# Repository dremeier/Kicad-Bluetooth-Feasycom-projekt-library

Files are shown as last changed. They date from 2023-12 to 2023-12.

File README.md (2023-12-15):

# Kicad-Bluetooth-Feasycom-projekt-library
KiCad 7 Library for the FSC-BT1026 Module and schematic with FSC-BT1026 and PCM5102.
The Feasycom module is a fantastic choice!
It is easy to control via UART, I2C and has I2S Audio bus as well direct SPDIF per default so no deep programming is necessary.
The Documentation is perfect and you can have a cheap experimental Board in Arduino-UNO format.

hope it is usefull for someone, 
enjoiy!

[Example Bluetooth schematic](https://github.com/dremeier/Kicad-Bluetooth-Feasycom-projekt-library/blob/main/Bluetooth_FSC-BT1026x_project/Documents/Bluetooth_PCM5102_Circuit.pdf)
<object data="https://github.com/dremeier/Kicad-Bluetooth-Feasycom-projekt-library/blob/main/Bluetooth_FSC-BT1026x_project/Documents/Bluetooth_PCM5102_Circuit.pdf" type="application/pdf" width="100%">
</object>

## KiCad 3D-Package
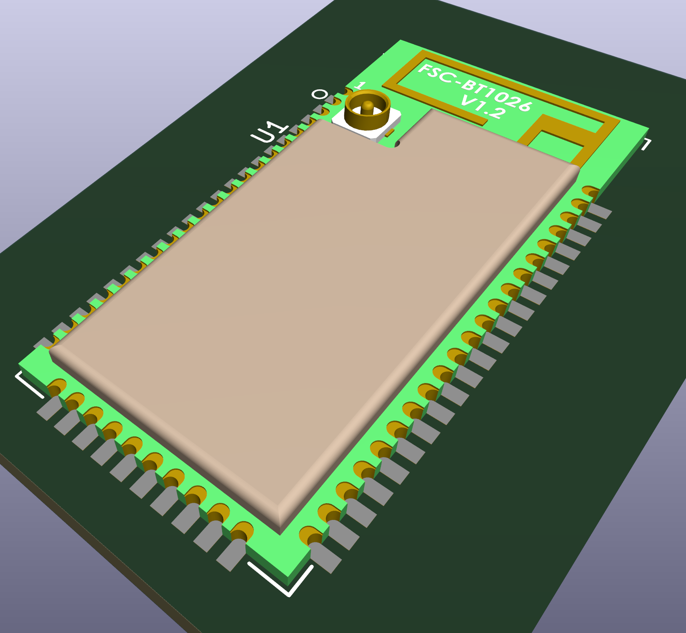
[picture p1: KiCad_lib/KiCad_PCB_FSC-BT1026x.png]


## KiCad Projekt with the Feasycom Bluetooth Module (BMW-IbusTrx-Teensy)


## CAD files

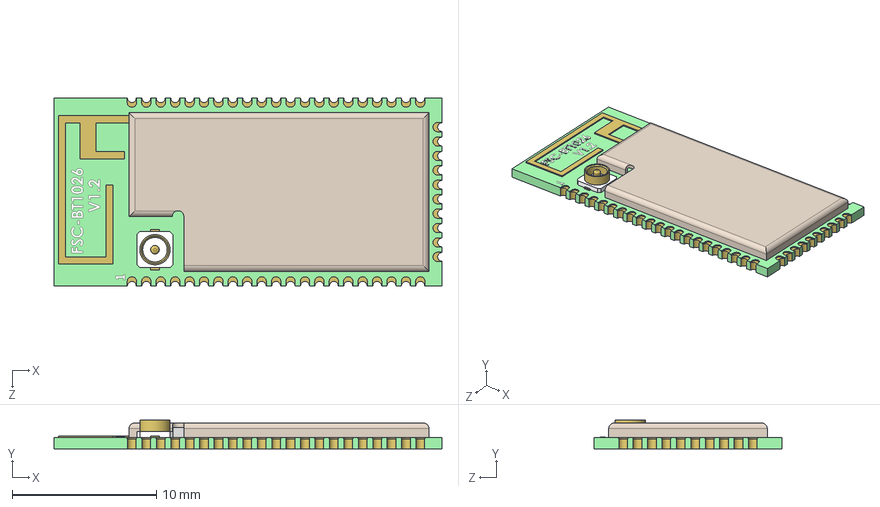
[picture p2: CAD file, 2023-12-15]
KiCad_lib/FSC-BT1026.STEP
26.9 x 2.00 x 13.0 mm

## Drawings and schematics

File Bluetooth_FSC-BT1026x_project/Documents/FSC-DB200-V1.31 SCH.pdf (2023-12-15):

6 | 5 | 4 | 3 | 2 | 1

D

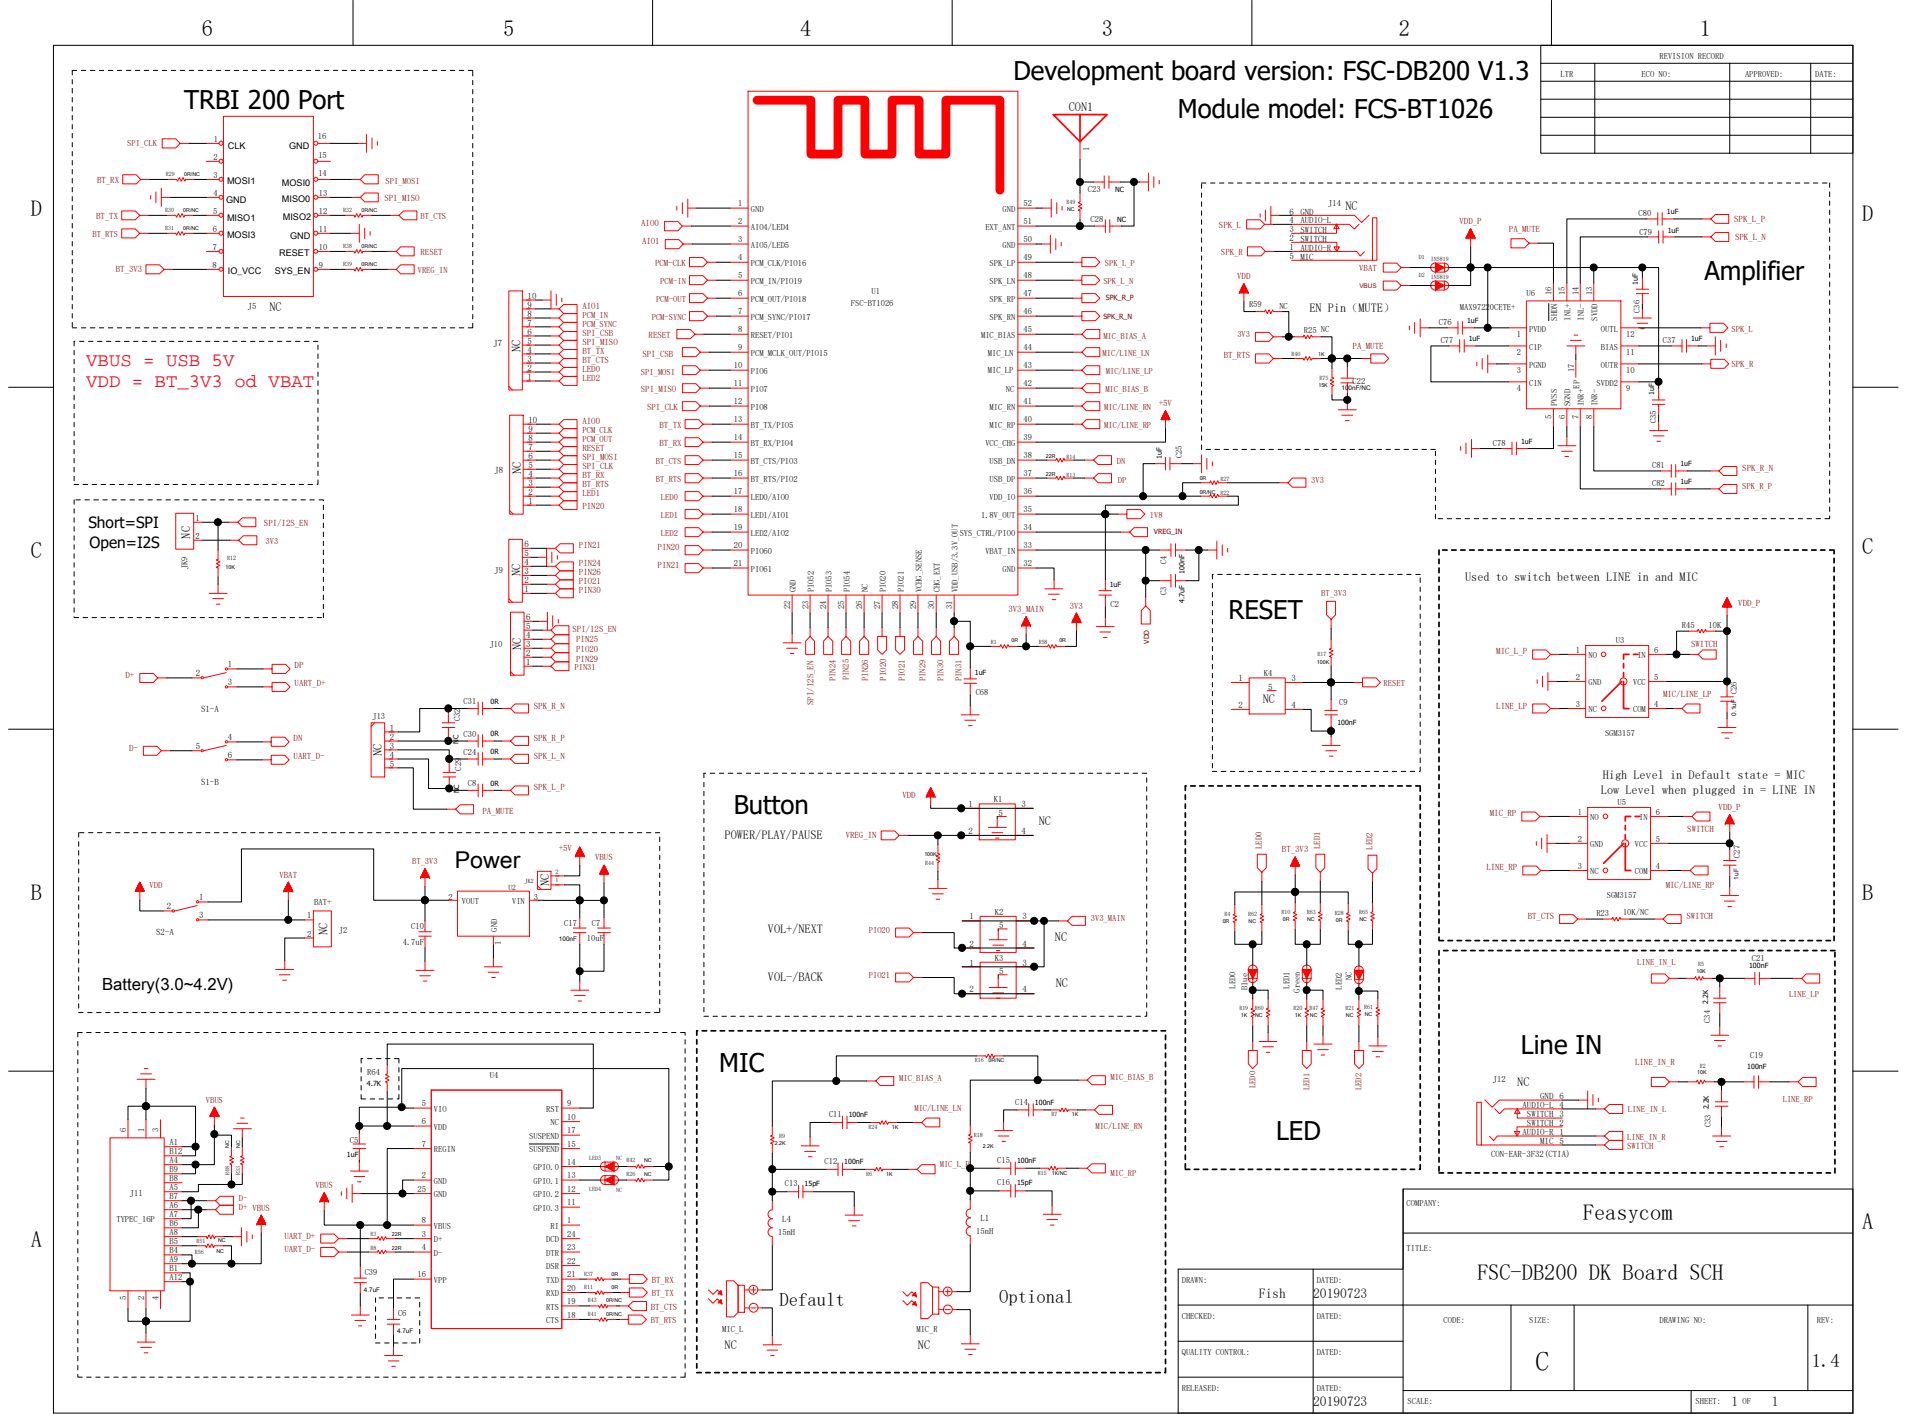
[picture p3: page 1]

Development board version: FSC-DB200 V1.

Used to switch between LINE in and MIC

High Level in Default state = MIC
Low Level when plugged in = LINE IN

FSC-DB200 DK Board SCH

CHECKED: | DATED: | CODE: | SIZE: C | DRAWING NO: | REV: 1.4

QUALITY CONTROL: | DATED:

RELEASED: | DATED: 20190723

SCALE: | SHEET: 1 OF 1

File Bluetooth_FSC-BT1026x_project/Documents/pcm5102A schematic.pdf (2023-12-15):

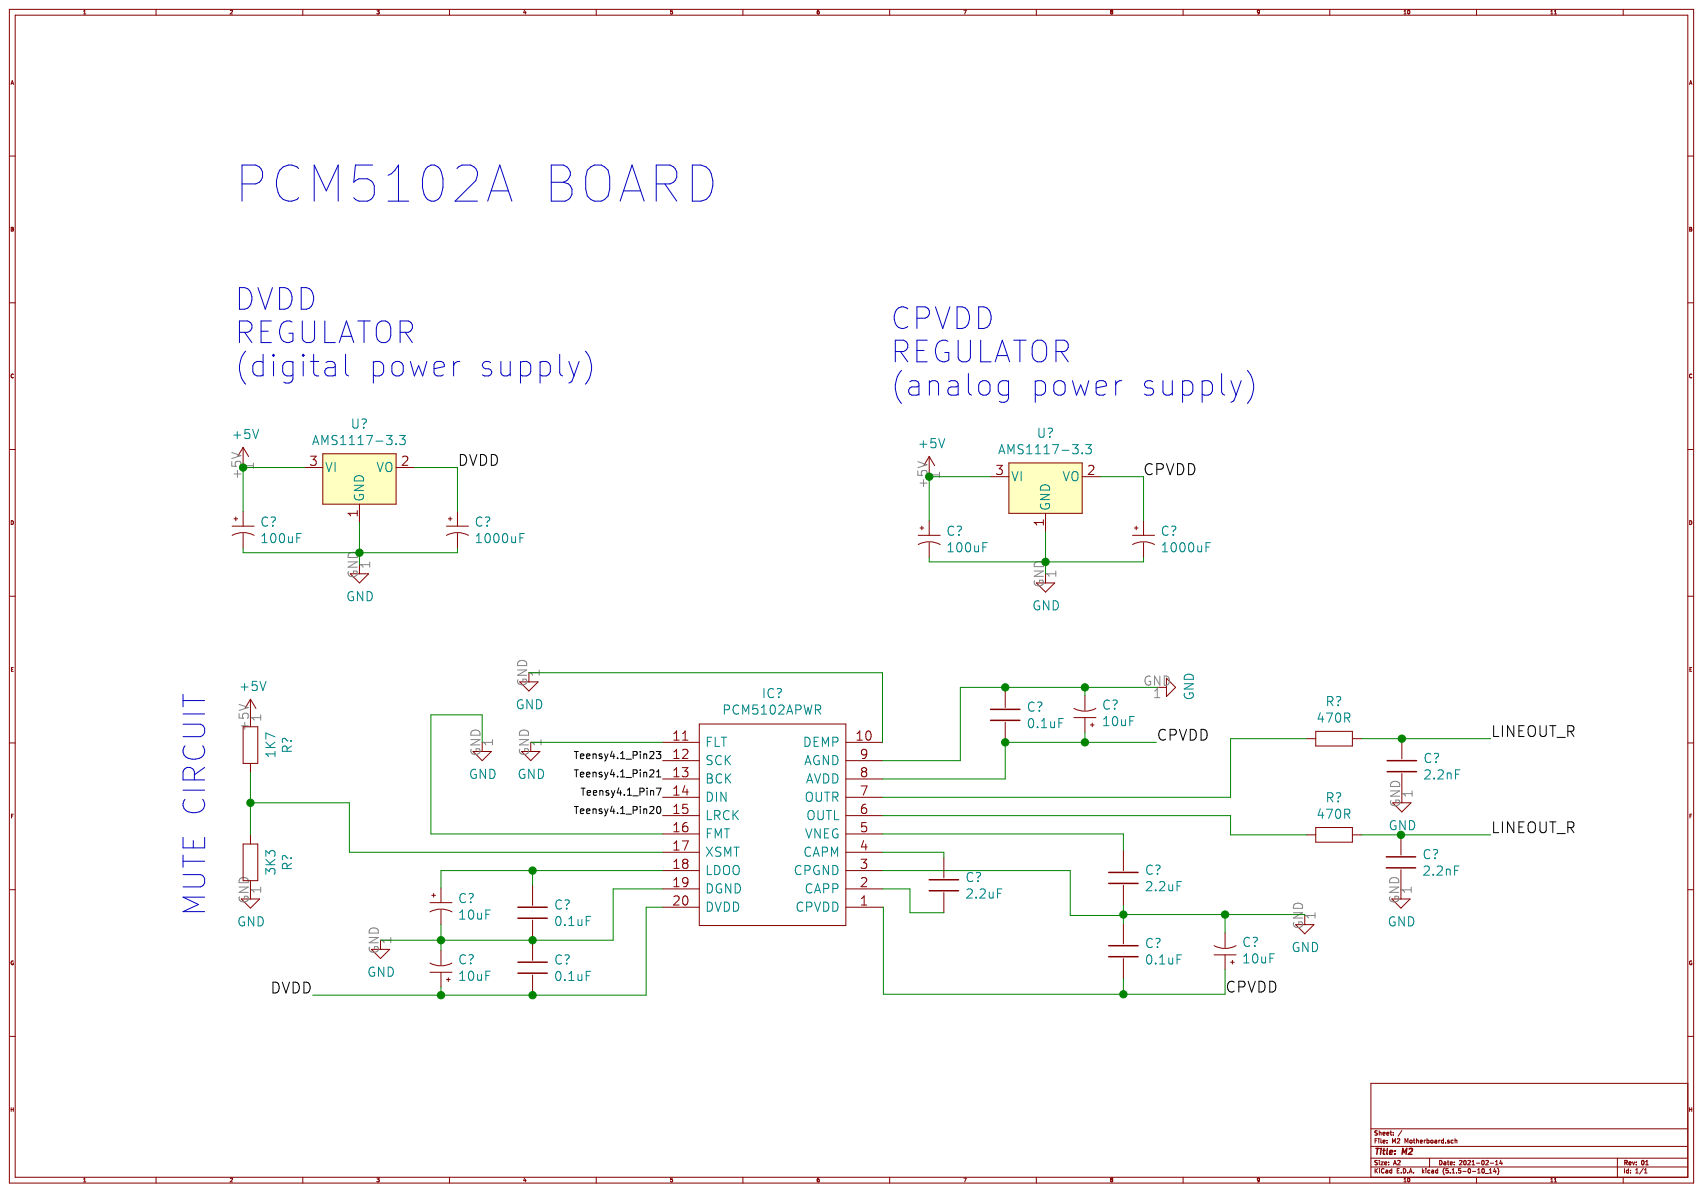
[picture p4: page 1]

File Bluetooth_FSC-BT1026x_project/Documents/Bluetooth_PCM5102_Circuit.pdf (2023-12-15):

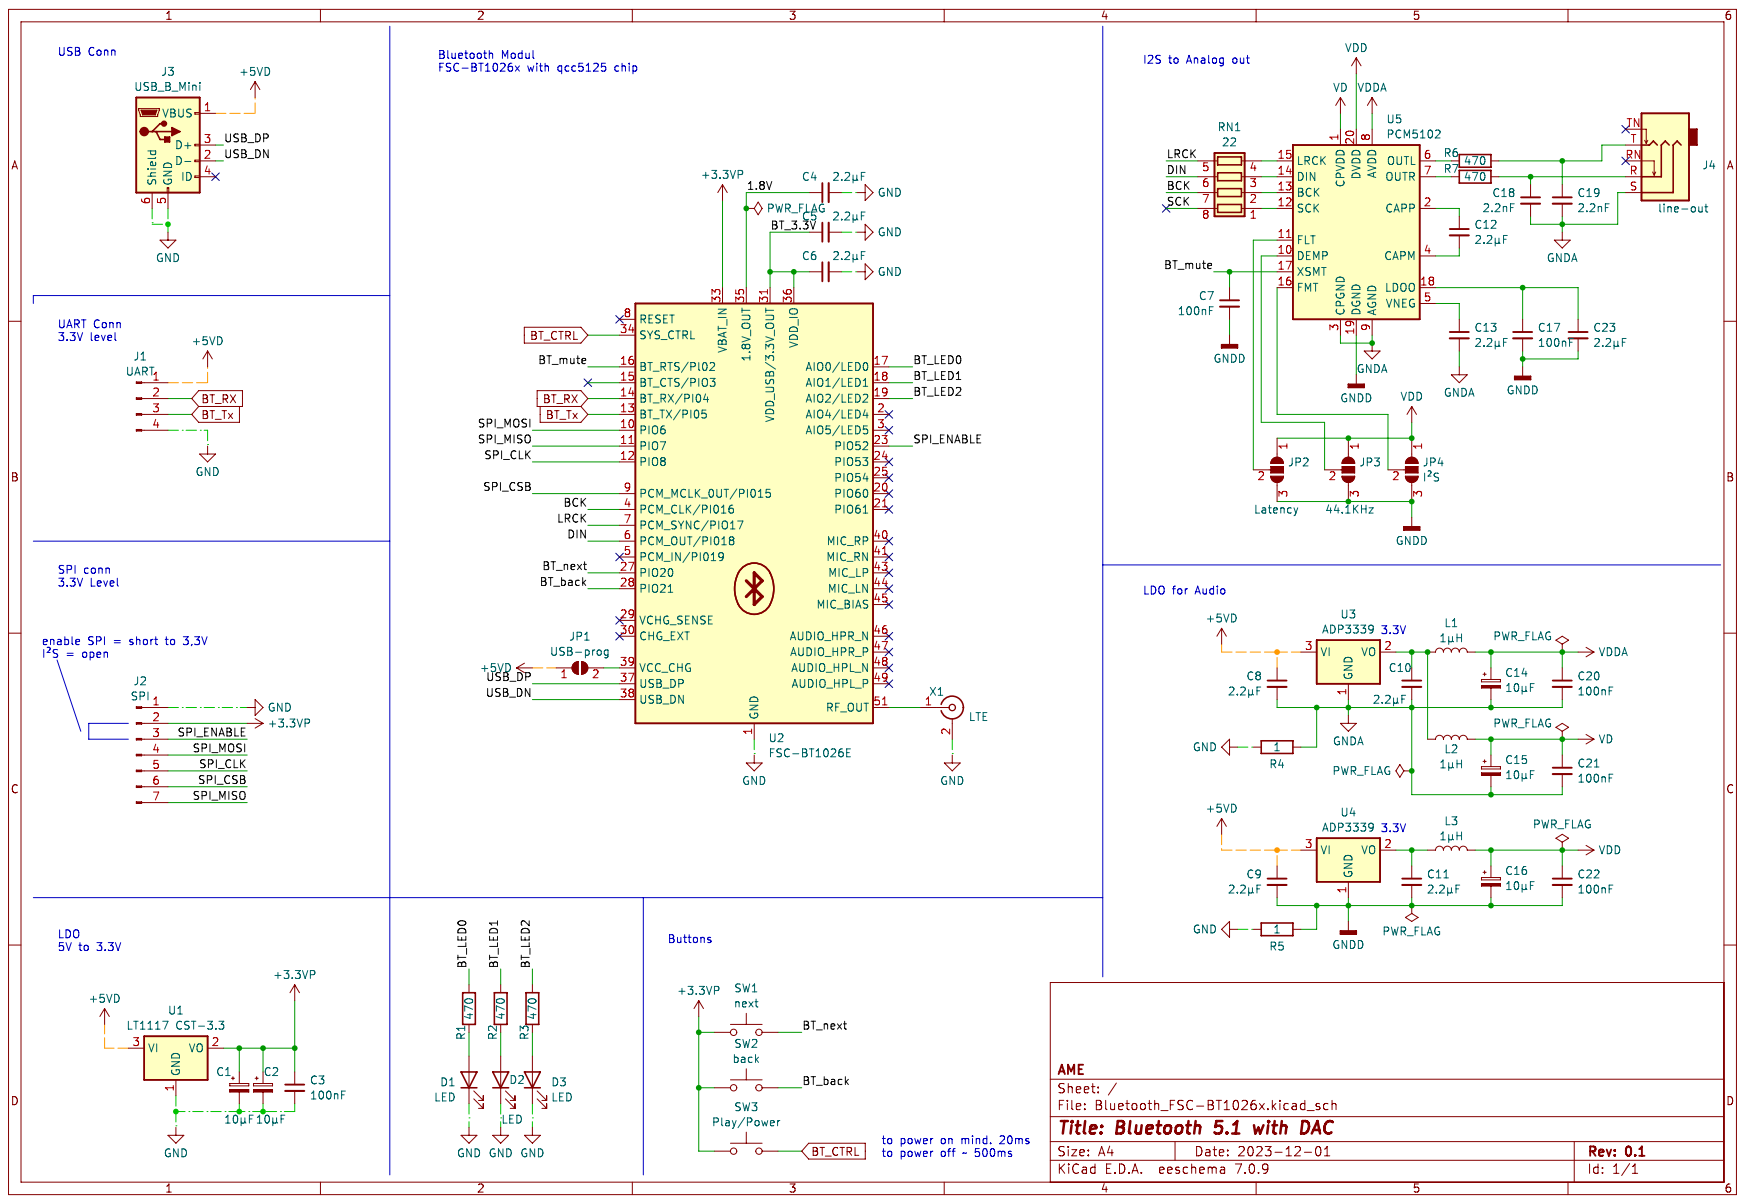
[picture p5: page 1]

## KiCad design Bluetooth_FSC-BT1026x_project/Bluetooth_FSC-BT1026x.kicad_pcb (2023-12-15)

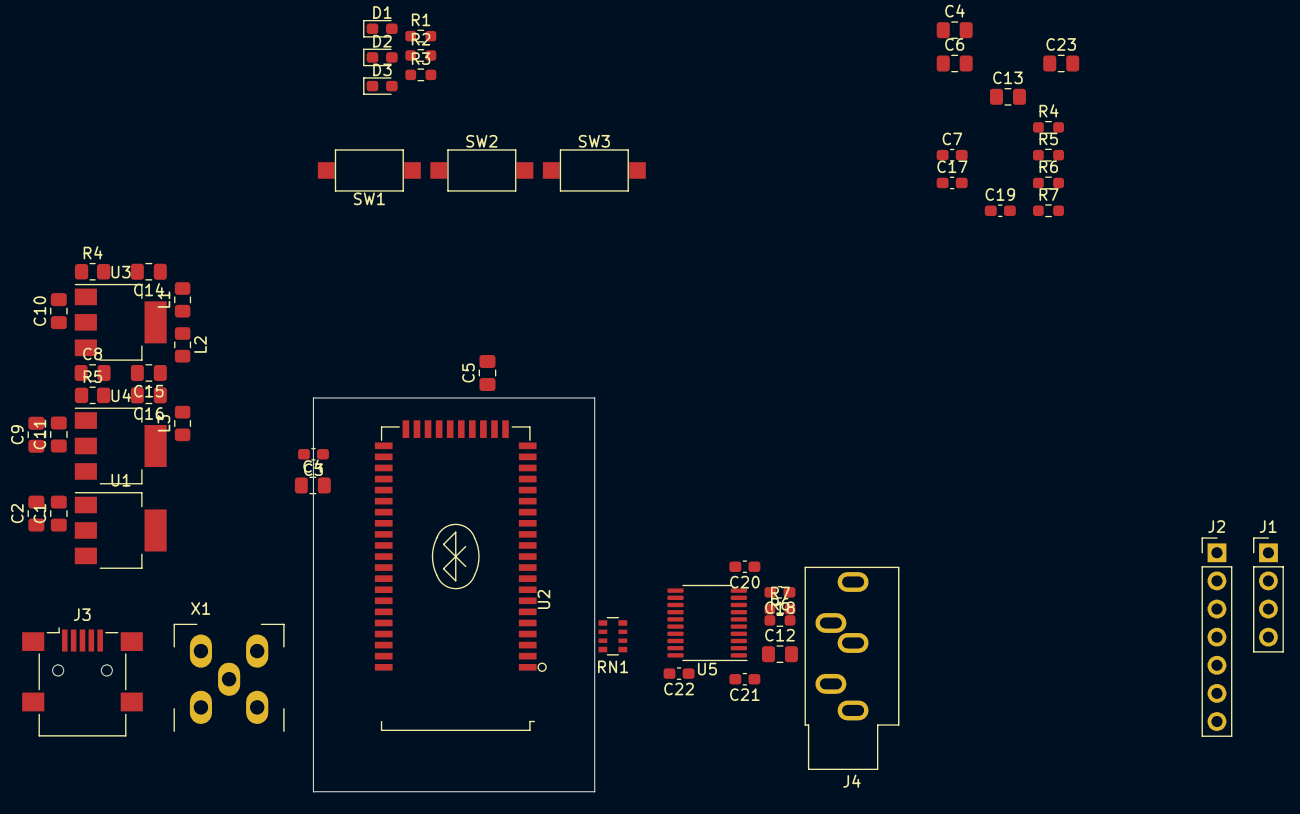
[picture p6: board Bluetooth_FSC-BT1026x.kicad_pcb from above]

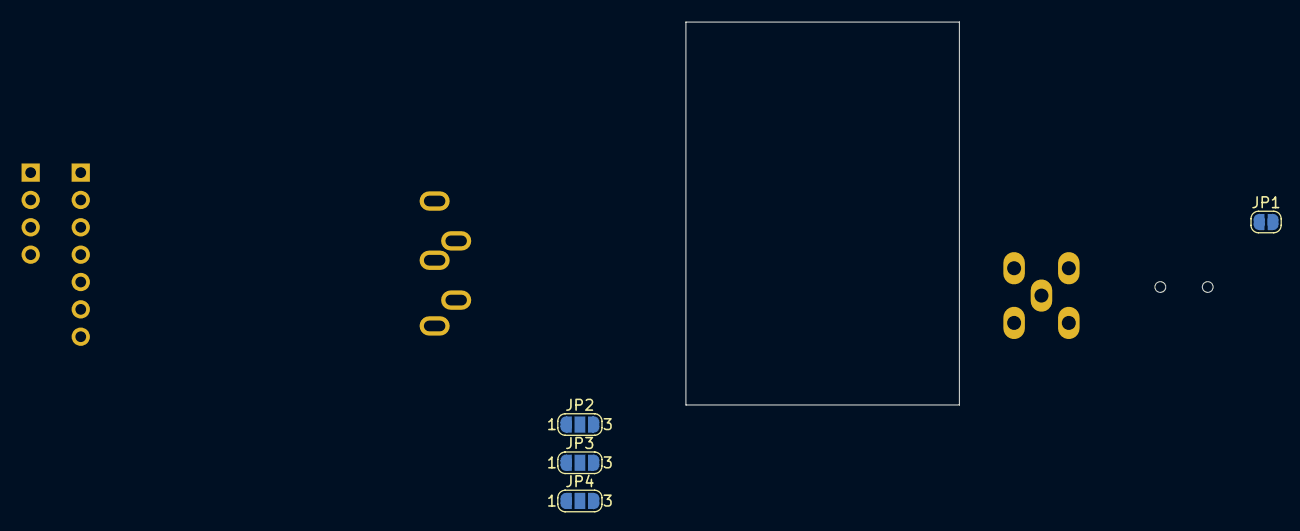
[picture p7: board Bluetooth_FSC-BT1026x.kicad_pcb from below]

Board: 2 copper layers, 59 parts (4 on the bottom side), 52 nets, no tracks yet.

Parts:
C1, C2, C14, C15, C16: 10μF; C_0805_2012Metric_Pad1.18x1.45mm_HandSolder
C3, C7, C17, C20, C21, C22: 100nF; C_0603_1608Metric_Pad1.08x0.95mm_HandSolder
C4, C4#2, C5, C6, C8, C9, C10, C11, C12, C13, C23: 2.2μF; C_0805_2012Metric_Pad1.18x1.45mm_HandSolder
C18, C19: 2.2nF; C_0603_1608Metric_Pad1.08x0.95mm_HandSolder
D1, D2, D3: LED; LED_0603_1608Metric_Pad1.05x0.95mm_HandSolder
J1: UART; PinHeader_1x04_P2.54mm_Vertical
J2: SPI; PinHeader_1x07_P2.54mm_Vertical
J3: USB_B_Mini; USB_Mini-B_Lumberg_2486_01_Horizontal
J4: line-out; Jack_3.5mm_CUI_SJ1-3535NG_Horizontal
JP1: USB-prog; SolderJumper-2_P1.3mm_Open_RoundedPad1.0x1.5mm
JP2: Latency; SolderJumper-3_P1.3mm_Open_RoundedPad1.0x1.5mm_NumberLabels
JP3: 44.1KHz; SolderJumper-3_P1.3mm_Open_RoundedPad1.0x1.5mm_NumberLabels
JP4: I²S; SolderJumper-3_P1.3mm_Open_RoundedPad1.0x1.5mm_NumberLabels
L1, L2, L3: 1μH; L_0805_2012Metric_Pad1.15x1.40mm_HandSolder
R1, R2, R3, R6#2, R7: 470; R_0603_1608Metric_Pad0.98x0.95mm_HandSolder
R4, R5, R6, R7#2: 22; R_0603_1608Metric_Pad0.98x0.95mm_HandSolder
R4#2, R5#2: 1; R_0805_2012Metric_Pad1.20x1.40mm_HandSolder
RN1: 22; R_Array_Convex_4x0603
SW1: next; SW_SPST_CK_RS282G05A3
SW2: back; SW_SPST_CK_RS282G05A3
SW3: Play/Power; SW_SPST_CK_RS282G05A3
U1: LT1117 CST-3.3; SOT-223-3_TabPin2
U2: FSC-BT1026E; FSC-BT1026x
U3, U4: ADP3339; SOT-223-3_TabPin2
U5: PCM5102; TSSOP-20_4.4x6.5mm_P0.65mm
X1: LTE; CONN_Fakra_DeLOCK_90°

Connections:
+3.3VP: C1.1, C2.1, C3.1, J2.2, SW1.1, SW2.1, SW3.1, U1.2 (VO), U2.33 (VBAT_IN)
+5VD: C8.1, C9.1, J1.1, J3.1 (VBUS), JP1.1 (A), U1.3 (VI), U3.3 (VI), U4.3 (VI)
/1.8V: C4.1, U2.35 (1.8V_OUT)
/BCK: R6.1, RN1.7 (R2.2), U2.4 (PCM_CLK/PI016)
/BT_3.3V: C5.1, C6.1, U2.31 (VDD_USB/3.3V_OUT), U2.36 (VDD_IO)
/BT_LED0: R1.2, U2.17 (AIO0/LED0)
/BT_LED1: R2.2, U2.18 (AIO1/LED1)
/BT_LED2: R3.2, U2.19 (AIO2/LED2)
/BT_back: SW2.2, U2.28 (PIO21)
/BT_mute: C7.1, U2.16 (BT_RTS/Pl02), U5.17 (XSMT)
/BT_next: SW1.2, U2.27 (PIO20)
/DIN: R5.1, RN1.6 (R3.2), U2.6 (PCM_OUT/PI018)
/LRCK: R4.1, RN1.5 (R4.2), U2.7 (PCM_SYNC/PIO17)
/SCK: R7#2.1, RN1.8 (R1.2)
/SPI_CLK: J2.5, U2.12 (PIO8)
/SPI_CSB: J2.6, U2.9 (PCM_MCLK_0UT/PI015)
/SPI_ENABLE: J2.3, U2.23 (PIO52)
/SPI_MISO: J2.7, U2.11 (PIO7)
/SPI_MOSI: J2.4, U2.10 (PIO6)
/USB_DN: J3.2 (D-), U2.38 (USB_DN)
/USB_DP: J3.3 (D+), U2.37 (USB_DP)
BT_CTRL: SW3.2, U2.34 (SYS_CTRL)
BT_RX: J1.2, U2.14 (BT_RX/PI04)
BT_Tx: J1.3, U2.13 (BT_TX/PI05)
GND: C1.2, C2.2, C3.2, C4.2, C4#2.1, C5.2, C6.2, D1.1 (K), D2.1 (K), D3.1 (K), J1.4, J2.1, J3.5 (GND), J3.6 (Shield), R4#2.1, R5#2.1, U1.1 (GND), U2.1 (GND), U2.22 (GND), U2.32 (GND), U2.50 (GND), U2.52 (GND), X1.2 (Ext)
GNDA: C8.2, C10.2, C13.2, C14.2, C15.2, C18.2, C19.2, C20.2, C21.2, J4.S, R4#2.2, U3.1 (GND), U5.3 (CPGND), U5.9 (AGND)
GNDD: C7.2, C9.2, C11.2, C16.2, C17.2, C22.2, C23.2, JP2.3 (B), JP3.3 (B), JP4.3 (B), R5#2.2, U4.1 (GND), U5.19 (DGND)
unnamed: C18.1, J4.R, R7.2
unnamed: C19.1, J4.T, R6#2.2
unnamed: D1.2 (A), R1.1
unnamed: D2.2 (A), R2.1
unnamed: D3.2 (A), R3.1
unnamed: JP1.2 (B), U2.39 (VCC_CHG)
unnamed: JP2.2 (C), U5.11 (FLT)
unnamed: JP3.2 (C), U5.10 (DEMP)
unnamed: JP4.2 (C), U5.16 (FMT)
unnamed: RN1.1 (R1.1), U5.12 (SCK)
unnamed: RN1.2 (R2.1), U5.13 (BCK)
unnamed: RN1.3 (R3.1), U5.14 (DIN)
unnamed: RN1.4 (R4.1), U5.15 (LRCK)
unnamed: U2.51 (RF_OUT), X1.1 (In)
unnamed: C10.1, L1.1, L2.1, U3.2 (VO)
unnamed: C11.1, L3.1, U4.2 (VO)
unnamed: C12.2, U5.4 (CAPM)
unnamed: C12.1, U5.2 (CAPP)
unnamed: C17.1, C23.1, U5.18 (LDOO)
unnamed: R6#2.1, U5.6 (OUTL)
unnamed: R7.1, U5.7 (OUTR)
unnamed: C13.1, U5.5 (VNEG)
VD: C15.1, C21.1, L2.2, U5.1 (CPVDD)
VDD: C16.1, C22.1, JP2.1 (A), JP3.1 (A), JP4.1 (A), L3.2, U5.20 (DVDD)
VDDA: C14.1, C20.1, L1.2, U5.8 (AVDD)
